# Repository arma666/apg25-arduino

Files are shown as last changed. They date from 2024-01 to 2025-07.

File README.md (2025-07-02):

## Блок управления пилетной горелкой АПГ-25 на основе esp32



Данный блок сделан в экспериментальных целях ради интереса и для хобби. До этого никогда не имел дела с ардуино-лайк, не с паяльником. Так что проект мягко говоря сырой, есть что ещё допиливать. Но тестирование прошёл и он работает.

---

ESP32 имеет встроенныймодуль wifi, но я не использовал его. Мне была принципиальна работа сети по кабелю. Но, если кому-то нужно, такая возможность есть, и в этом случае модуль W5500 можно не покупать.

Делал для своей АПГ-25, но подойдёт на горелки любой мощности.

---

#### _Особености_

*   Все компоненты - готовые модули. Они не распаяны на плате, а вставлены в штыревые разъемы. При выходе из строя любой из них легко заменить.
*   Управление блоком по ethernet кабелю.
*   Простой api на основе get-запросов.

#### _Компоненты_

| Компонент | Ссылка |
| --- | --- |
| ESP32 | [link](https://market.yandex.ru/product--maketnaia-plata-nodemcu-esp32-esp-wroom-32-ch340-type-c-wifi-bluetooth-lua-sverkhnizkoe-energopotreblenie/1790648827?sku=1018809108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) |
| Датчик обнаружения пламени LM393, 4-контактный | [link](https://www.ozon.ru/product/datchik-obnaruzheniya-plameni-lm393-4-kontaktnyy-846693032/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) |
| OLED дисплей 0.96" 128x64, I2C | [link](https://www.ozon.ru/product/oled-displey-0-96-128x64-i2c-goluboy-832377824/) |
| Модуль регулятора напряжения N-MOS | [link](https://www.ozon.ru/product/regulyator-skorosti-dvigatelya-xy-mos-regulyator-napryazheniya-n-mos-pereklyuchatel-1228912589/) |
| Сетевой модуль W5500 | [link](https://market.yandex.ru/product--setevoi-modul-w5500-tcp-ip-stm32-ethernet-dlia-arduino-n/1824023690?sku=101968565885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) |
| Модуль реле твердотельное 12 вольт 2 канала высокоуровневое. | [link](https://www.ozon.ru/product/2-kanalnyy-12v-vysokourovnevoe-upravlenie-postoyannym-tokom-tverdotelnyy-releynyy-1269808418/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). |
| 1-канальный релейный модуль 5V. | [link](https://www.ozon.ru/product/1-kanalnyy-releynyy-modul-5v-5-volt-1-kanal-modul-rele-1-kanal-nagruzka-max-ac-250v-10a-dc-30v-1269506499) |
| Печатная макетная плата для пайки двухсторонняя 9\*15см / зеленая плата под пайку универсальная | [link](https://www.ozon.ru/product/pechatnaya-maketnaya-plata-dlya-payki-dvuhstoronnyaya-9-15sm-zelenaya-plata-pod-payku-universalnaya-1067054329/) |
| Штыревые однорядные разъемы на плату МАМА (PBS-40) 40 pin 2.54 мм, 10 штук | [link](https://www.ozon.ru/product/shtyrevye-odnoryadnye-razemy-na-platu-mama-pbs-40-40-pin-2-54-mm-10-shtuk-pld-razem-dlya-proektov-1051231516/) |
| Клеммная колодка KF235 с пружинным зажимом для пайки на плату 10 контактов | [link](https://www.ozon.ru/product/klemmnaya-kolodka-kf235-s-pruzhinnym-zazhimom-dlya-payki-na-platu-10-kontaktov-764072916/) |
| Клеммная колодка KF202 с пружинным зажимом для пайки на плату 6 контактов | [link](https://www.ozon.ru/product/klemmnaya-kolodka-kf202-s-pruzhinnym-zazhimom-dlya-payki-na-platu-6-kontaktov-764413414/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) |
| Датчик температуры DS18B20 + Модуль для подключения | [link](https://www.ozon.ru/product/datchik-temperatury-ds18b20-modul-dlya-podklyucheniya-832438319/) |
| Блок питания 12В 2А |   |
| Кнопка | [link](https://www.ozon.ru/product/taktovaya-knopka-dip-6mm-h-6mm-h-5mm-kan0611-0431b-komplekt-10sht-1298579180/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) |

#### _Схема_

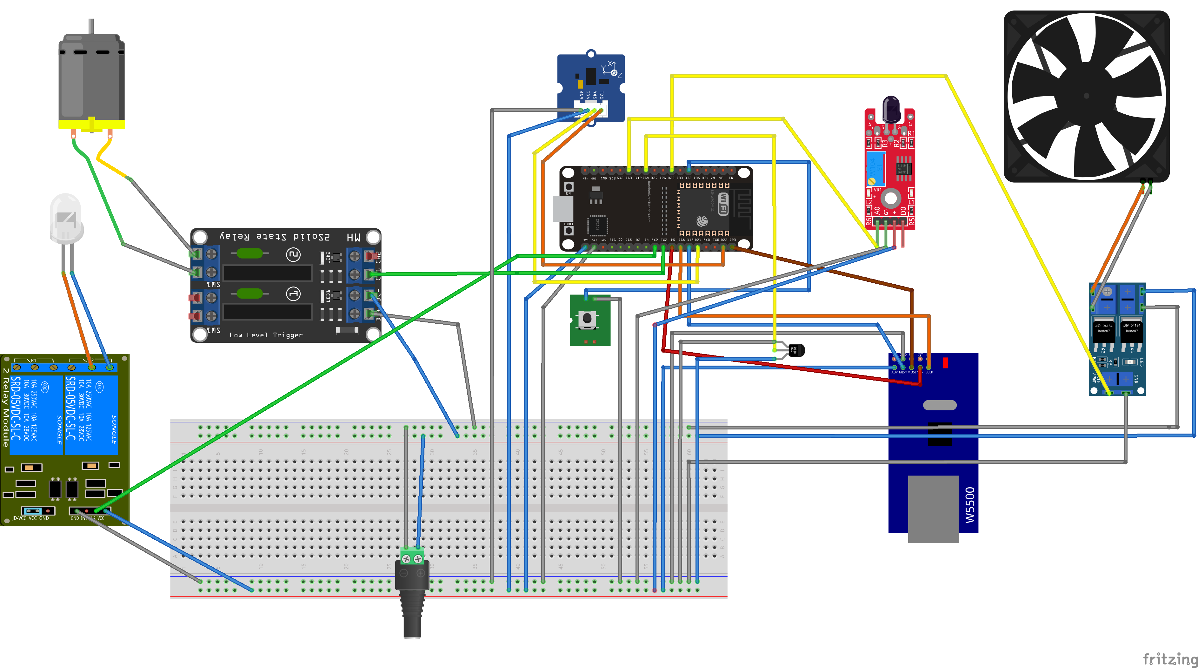
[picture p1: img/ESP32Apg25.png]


Так же схема есть в файле [ESP32Apg25.fzz](https://github.com/arma666/apg25-arduino/blob/main/ESP32Apg25.fzz) для fritzing.

#### _Индикация_

На олед-дисплее простая индикация. Имеется обратный отчёт подкидывания/лампы.   

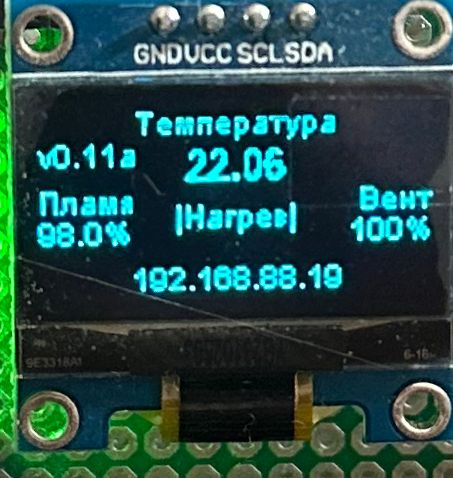
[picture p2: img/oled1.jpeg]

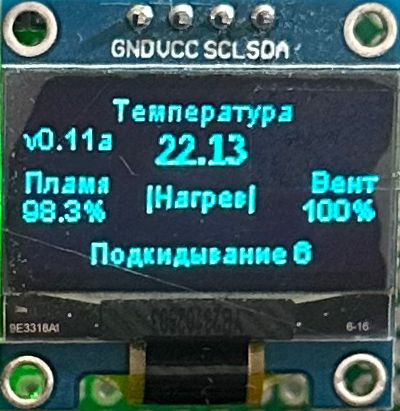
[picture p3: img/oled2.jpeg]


#### Веб-интерфейс

Интуитивно понятный и минималистский. Сам интерфейс храниться на github, и загружается динамически. И как следствие можно его менять не перепрошивая esp32 и даже не выключая. 

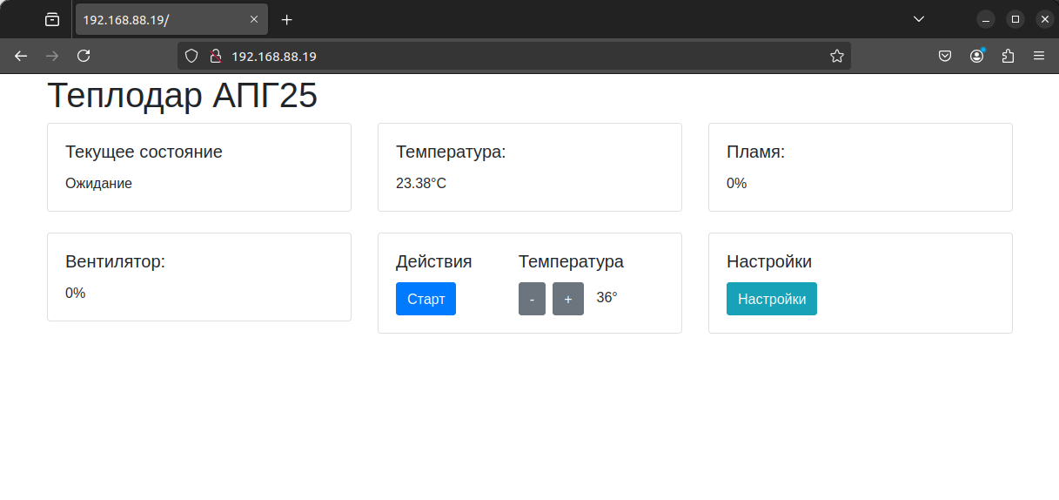
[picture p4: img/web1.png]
 

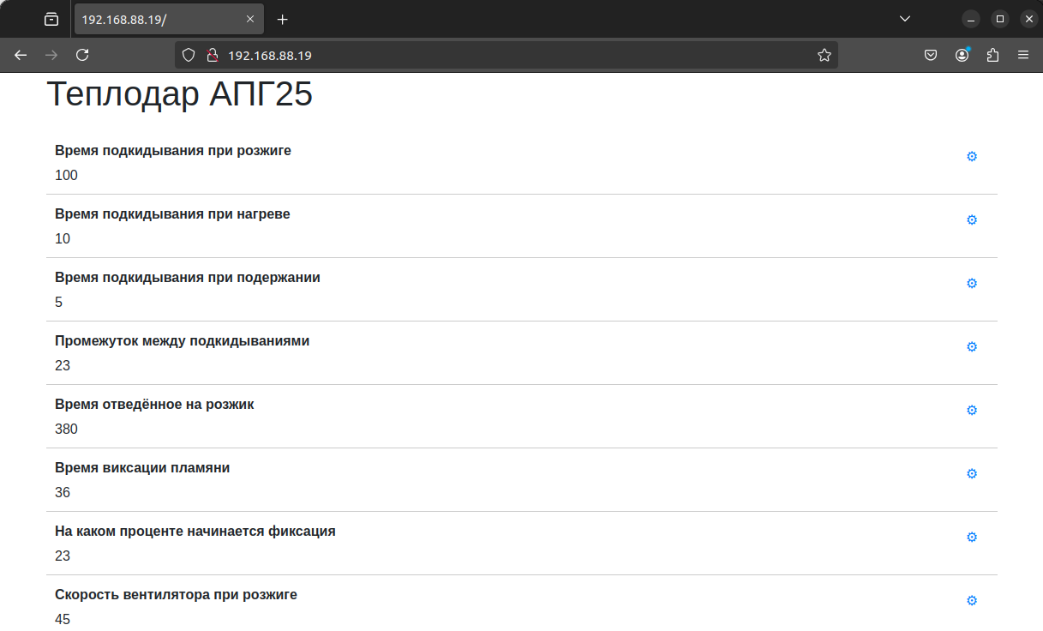
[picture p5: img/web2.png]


#### _API_

_(дополнить)_

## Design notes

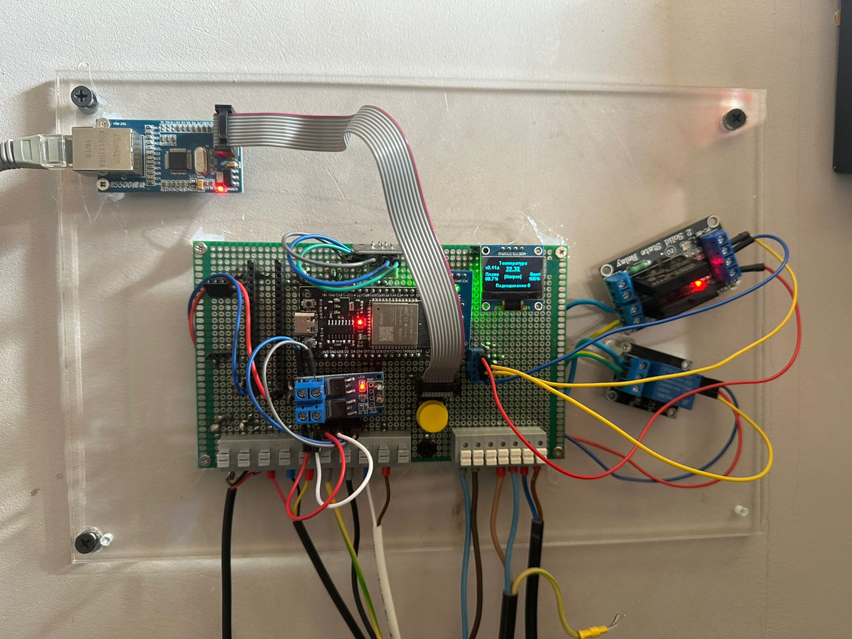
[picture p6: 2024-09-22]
img/full.jpeg

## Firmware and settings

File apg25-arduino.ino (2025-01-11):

String VERSION="v0.122a";

#include <SSD1306Wire.h>
#include "fontsRus.h"
#include "fonts.h"
//#include <EEPROM.h>
#include <ArduinoJson.h>
#include <SPIFFS.h>
#include <SPI.h>
#include <Ethernet2.h>
// Перезагрузка интерфейса
unsigned long lastResetTime = 0;
unsigned long resetInterval = 900000;   // Интервал перезагрузки (15 минут)
//


//Расход
unsigned long throwTime = 0; //Накопление
unsigned long throwTimemillis = 0;
float throwPersent = 0;
///////
unsigned long trozhTemp = 0;

byte rAddr= 0;
SSD1306Wire display(0x3c, SDA, SCL); // SDA - IO5 (D1), SCL - IO4 (D2) 

// Температура ------------------------->
#include <OneWire.h>
OneWire  ds(14);
byte addr[8];
float temperVal = 0; // Глобальная температура
//<---------------------------------

//Настройки
struct OPT {
  unsigned long  Tshnek;
  unsigned long  Trozhik;
  unsigned long  Tflamefix;
  unsigned long  waitTshnek;
  unsigned long Tflame;//Сколько времени нет пламени
  unsigned long Tvizh;
  unsigned long  TFlame; 
  unsigned long TTemp;
  unsigned long timer500;
  unsigned long Tbtn;
  float flamePersent = 0;
  byte vspeed = 0;
  String defIP = "-.-.-.-";
  unsigned long countTimer;
  byte rozhikCount = 0;
  boolean isnet = false; 
  /*
Режимы - -
  0 - Ожидание
  1 - Розжик
  2 - Нагрев
  3 - Поддержание
  4 - Выжигание
  5 - Ошибка розжига
  6 - Ошибка пламени
*/
  byte regim;
  byte prregim;
  boolean isstart = true;
};
OPT opt;
//Настройки ------------>
struct SETTINGS {
  byte troz_sh; //Время подкидывания при розжиге 
  byte tnag_sh; //Время подкидывания при нагреве
  byte tpod_sh; //Время подкидывания при подержании
  byte tsh_st; //Промежуток между подкидываниями
  unsigned long troz; //Время отведённое на розжик
  byte fl_fix; //Время виксации пламяни
  byte tfl; //На каком проценте начинается фиксация
  byte vroz; //скорость вентилятора при розжиге
  byte v_nag; //скорость вентилятора при нагреве
  byte v_pod; //скорость вентилятора при поддержании
  byte v_og; //скорость вентилятора при ожидании
  byte temp; //Установка температуры
  byte gister; //Гистерезис
  byte t_vizh; //Время выжигания после пламя = 0
  byte t_max; //температура перегрева
};

SETTINGS defaultSettings = {
  90, //Время подкидывания при розжиге 
  11, //Время подкидывания при нагреве
  4, //Время подкидывания при подержании
  27, //Промежуток между подкидываниями
  1200, //Время отведённое на розжик
  100, //Время фиксации пламяни
  20, //На каком проценте начинается фиксация
  75, //скорость вентилятора при розжиге
  100, //скорость вентилятора при нагреве
  80, //скорость вентилятора при поддержании
  0, //скорость вентилятора при ожидании
  49, //Установка температуры
  4, //Гистерезис
  180, //Время выжигания после пламя = 0
  70 //температура перегрева
};
SETTINGS conf; 

// Датчик огня ----------->
byte analogPin = 13;
//String flame = "0";
//<------------------------

// Реле ------------>
const byte shnek = 17;
const byte lampa = 16;
bool shnekStart = false;
bool lampaStart = false;
//<------------------------

// Кнопка ----------->
bool bflag = false;
byte bpin = 32;
//<------------------------

// Вентилятор ----------->
const byte vent = 25;
byte vspeed = 0; //скорость вентилятора в процентах
byte vspeedtemp = 0;
//<------------------------


// MAC-адрес вашего Arduino
byte mac[] = {0xDE, 0xAD, 0xBE, 0xEF, 0x29, 0xED};

// Создаем сервер на порту 80
EthernetServer server(80);
byte serverPort = 80;
EthernetClient client;


//Функция инициализации сети
void netstart(){
  //Serial.println("y");
  Ethernet.init(5);
  //Serial.println("x");
  if (Ethernet.begin(mac) == 0) {
    ////Serial.println("Failed to configure Ethernet using DHCP");
    // Некоторые дополнительные действия при ошибке
    opt.defIP="No ip :(";
    //for(;;);
  } else {
    //My IP address:
    opt.defIP = "";
    for (byte thisByte = 0; thisByte < 4; thisByte++) {
      opt.defIP+=Ethernet.localIP()[thisByte];
      if (thisByte < 3) {
        opt.defIP+=".";
      }
    }
    opt.isnet=true;
    // Начинаем слушать порт 80
    server.begin();
  }
}

void netreset(){
  if (millis() - lastResetTime >= resetInterval) {
      lastResetTime = millis();  
      netstart(); 
    }
}

int percentToValue(int percent) { //Функция перевода процентов в число для вкентилятора
  if (percent == 0){
    return 0;
  } else {
    return map(percent, 0, 100, 73, 255);
  }
}

//Запись режима
void rwrite(){
  File regim = SPIFFS.open("/regim", "w");
  regim.write(opt.regim);
  regim.close();

}
void rload(){
  File regim = SPIFFS.open("/regim", "r");
  if (!regim) {
    File regim = SPIFFS.open("/regim", "w");
    regim.write(0);
    regim.close();
  } else {
    opt.regim = regim.read();
    regim.close();
  }
}



void setup() {
  // esp_task_wdt_init();
  // esp_task_wdt_add(NULL);
  //Serial.begin(115200);
  //Сеть
  netstart();
  //Вентилятор
  pinMode(vent, OUTPUT);

  //Реле
  pinMode(lampa, OUTPUT);    
  pinMode(shnek, OUTPUT);  
  digitalWrite(lampa, LOW); // Выключаем реле
  digitalWrite(shnek, LOW); // Выключаем реле 
  //Читаем из памяти
  if (!SPIFFS.begin(true)) {
    //Serial.println("An error occurred while mounting SPIFFS");
    return;
  }
  
  if (!loadSettings()) {
    conf = defaultSettings;
    saveSettings();
  }
  
  //Кнопка
  pinMode(bpin, INPUT_PULLUP); 

  //Дисплей
  display.init(); //  Инициализируем дисплей
  display.flipScreenVertically(); // Устанавливаем зеркальное отображение экрана
  display.setFontTableLookupFunction(FontUtf8Rus);

  //Загрузка режима
  rload();

  //Проверяем пламя
  flameGet();
  checkstart();

}

void checkstart(){
  if (opt.flamePersent>0){ //Если есть плямя
    if (opt.regim == 2 || opt.regim == 3 ){ //Если до перезагрузки был режим 2 или 3
      opt.prregim = 14; //ВОзращаем печку в режим 
    }
    if (opt.regim == 4) { //Если стояло выжигание
      opt.prregim = 8;
    }
    if (opt.regim == 1){ //Если тоял розжик
      opt.prregim = 8;
    }
    if (opt.regim == 6) { //Если ошибка пламени при работе
      opt.prregim = 14;
    }
  } else { //Если пламени нет
     if (opt.regim == 2 || opt.regim == 3 || opt.regim == 6) { //Если до рестарта горело или ошибка пламени при работе, тогда розжик
      opt.regim = 1;
      opt.prregim = 10;
     } else {
      opt.regim = 0;
      opt.prregim = 0;
      opt.Tflame=0;
      shnekStart=false;
      lampaStart=false;
      vspeedtemp = 0;
     }
  }
  rwrite();

}

String x = "";
bool loadSettings() {
  File configFile = SPIFFS.open("/conf1.json", "r");
  if (!configFile) {
    return false;
  }

  size_t size = configFile.size();
  if (size == 0) {
    return false;
  }

  std::unique_ptr<char[]> buf(new char[size]);
  configFile.readBytes(buf.get(), size);
  x=buf.get();
  StaticJsonDocument<1024> doc;
  DeserializationError error = deserializeJson(doc, buf.get());
  if (error) {
    //Serial.println("Failed to parse config file");
    return false;
  }

  conf.troz_sh = doc["troz_sh"] | defaultSettings.troz_sh;
  conf.tnag_sh = doc["tnag_sh"] | defaultSettings.tnag_sh;
  conf.tpod_sh = doc["tpod_sh"] | defaultSettings.tpod_sh;
  conf.tsh_st = doc["tsh_st"] | defaultSettings.tsh_st;
  conf.troz = doc["troz"] | defaultSettings.troz;
  conf.fl_fix = doc["fl_fix"] | defaultSettings.fl_fix;
  conf.tfl = doc["tfl"] | defaultSettings.tfl;
  conf.vroz = doc["vroz"] | defaultSettings.vroz;
  conf.v_nag = doc["v_nag"] | defaultSettings.v_nag;
  conf.v_pod = doc["v_pod"] | defaultSettings.v_pod;
  conf.v_og = doc["v_og"] | defaultSettings.v_og;
  conf.temp = doc["temp"] | defaultSettings.temp;
  conf.gister = doc["gister"] | defaultSettings.gister;
  conf.t_vizh = doc["t_vizh"] | defaultSettings.t_vizh;
  conf.t_max = doc["t_max"] | defaultSettings.t_max;
  
  

  configFile.close();
  return true;
}

void saveSettings() {
  File configFile = SPIFFS.open("/conf1.json", "w");
  if (!configFile) {
    //Serial.println("Failed to open config file for writing");
    return;
  }

  StaticJsonDocument<1024> doc;
  doc["troz_sh"] = conf.troz_sh;
  doc["tnag_sh"] = conf.tnag_sh;
  doc["tpod_sh"] = conf.tpod_sh;
  doc["tsh_st"] = conf.tsh_st;
  doc["troz"] = conf.troz;
  doc["fl_fix"] = conf.fl_fix;
  doc["tfl"] = conf.tfl;
  doc["vroz"] = conf.vroz;
  doc["v_nag"] = conf.v_nag;
  doc["v_pod"] = conf.v_pod;
  doc["v_og"] = conf.v_og;
  doc["temp"] = conf.temp;
  doc["gister"] = conf.gister;
  doc["t_vizh"] = conf.t_vizh;
  doc["t_max"] = conf.t_max;

  if (serializeJson(doc, configFile) == 0) {
    //Serial.println("Failed to write to config file");
  }

  configFile.close();
}



void Display(){
  display.clear(); // Очищаем экран
  display.setFont(ArialRus_Plain_10); // Шрифт кегль 10
  display.setTextAlignment(TEXT_ALIGN_CENTER);
  display.drawString(display.getWidth() / 2, 0, "Температура");
  display.setFont(Arimo_Bold_13);
  display.drawString(display.getWidth() / 2, 13, String(temperVal));
  //Версия
  display.setFont(ArialRus_Plain_10); 
  display.setTextAlignment(TEXT_ALIGN_LEFT);
  display.drawString(0, 10, VERSION);
  //Пламя
  display.setFont(ArialRus_Plain_10); 
  display.setTextAlignment(TEXT_ALIGN_LEFT);
  display.drawString(0, 25, "Пламя");
  display.drawString(0, 35, String(opt.flamePersent,1)+"%");
  //Вентилятор
  display.setTextAlignment(TEXT_ALIGN_RIGHT);
  display.drawString(display.getWidth(), 25, "Вент");
  display.drawString(display.getWidth(), 35, String(vspeed)+"%");
  //Режим
  String regimStr;
  switch (opt.regim) {
    case 0:
      regimStr = F("|Ожидание|");
    break;
    case 1:
      regimStr = "|Розжик "+String(opt.rozhikCount+1)+ "|";
    break;
    case 2:
      regimStr = F("|Нагрев|");
    break;
    case 3:
      regimStr = F("|Поддерж|");
    break;
    case 4:
      regimStr = F("|Выжигание|");
    break;
    case 5:
      regimStr = F("|Ошибка|");
    break;
    }
  display.setTextAlignment(TEXT_ALIGN_CENTER);
  display.drawString(display.getWidth() / 2, 30, regimStr);
  String status;
  switch (opt.prregim) {
    case 10:
      status = F("Подкидывание");
    break;
    case 11:
      status = "Подкидывание "+String(opt.countTimer);
    break;
    case 12:
      status = "Лампа "+String(opt.countTimer);
    break;
    case 13:
      status = F("Вижу пламя - фиксация");
    break;
    case 14:
      status = F("Разгорелось!");
    break;
    case 21:
      status = "Подкидывание "+String(opt.countTimer);
    break;
    case 22:
      status = "Подкидывание "+String(opt.countTimer);
    break;
    case 31:
      status = "Подкидывание "+String(opt.countTimer);
    break;
    case 32:
      status = "Подкидывание "+String(opt.countTimer);
    break;
    case 80:
      status = "Перегрев!!!!";
    break;
    default:
      status = opt.defIP;
  }
  display.drawString(display.getWidth() / 2, 50, status);

  display.display(); // Выводим на экран
}



void loop() {
  if (opt.isnet)
  {
    web();
  } else 
  {
    netstart();
  }
  
  
  
  if (millis() - opt.TTemp >= 5000) {
    netreset();
    opt.TTemp = millis();
    temperVal = TempGetTepr();
    //Если перегрев
    if (temperVal>conf.t_max) {
      opt.prregim = 80;
    }
  }
  
  if (millis() - opt.timer500 >= 500) {
    opt.timer500=millis();
    flameGet();
    rele();
    Display();
    Vent();
    flamecheck();
    control();
  }

  //блок кнопки
  bool btnState = !digitalRead(bpin);
  if (btnState && !bflag && millis() - opt.Tbtn > 100) { //Кнопку нажали
    bflag = true;
    opt.Tbtn = millis();
  } 
  if (!btnState && bflag && millis() - opt.Tbtn > 100) {  //Кнопку отпустили
    bflag = false;
    opt.Tbtn = millis();
    pressputton();
  }
}


//Функция проверки не патух ли котел
void flamecheck(){
  if (opt.regim && opt.regim!=1 && opt.regim!=5 && opt.regim!=4 && !opt.Tflame){
    if (opt.flamePersent < conf.tfl) {
          //Если пламя пропало, то возможно его забросало и оно разгориться, ждём 45 секунд
          opt.Tflame=millis();
    }
  }
  if (opt.Tflame && opt.Tflame+(45*1000L)<millis()){
    if (opt.flamePersent < conf.tfl){
      //не разожглось, уходим в ошибку
      shnekStart=false;
      opt.prregim = 19;
      opt.regim = 6;
      rwrite();
      lampaStart=false;
      opt.Tflame=0;
      ESP.restart();
    } else {
      opt.Tflame=0;
    }
  }
}


//Основная функция управления 
void control() {
  ////Serial.println(String(opt.prregim));
  switch (opt.prregim) {
      //Перегрев
      case 80:
        shnekStart=false;
        lampaStart=false;
        vspeedtemp = 100;
      break;
      case 8: //Выжигание, ждём когда погаснет
        if (opt.flamePersent == 0) {
          opt.Tvizh = millis();
          opt.prregim = 9;
        }
      break;
      case 9: //
        if (opt.Tvizh+(conf.t_vizh*1000L)<millis()){
          opt.prregim = 0;
          opt.regim = 0;
          rwrite();
          shnekStart=false;
          lampaStart=false;
          vspeedtemp = 0;
          ESP.restart();
        }
      break;
      //10-11 подкидывание при розжиге
      case 10:
        if (opt.rozhikCount) {
            trozhTemp = 10;
        } else {
            trozhTemp = conf.troz_sh;
        }
        opt.prregim = 11;
        shnekStart=true;
        opt.Tshnek = millis();
        //opt.countTimer=trozhTemp;
      break;
      case 11:
        opt.countTimer=(opt.Tshnek+(trozhTemp*1000L) - millis())/1000;
        if (opt.Tshnek+(trozhTemp*1000L) < millis()) {
          shnekStart=false;
          lampaStart=true;
          vspeedtemp = conf.vroz;
          opt.prregim = 12;
          opt.Trozhik = millis();
        }
      break;
      //Подкидывание закончилось, лампа, ждём когда увидим пламя
      case 12:
        opt.countTimer=(opt.Trozhik+(conf.troz*1000L) - millis())/1000;
        //Лампа не больше 300 секунд
        // if (opt.Trozhik+300*1000L<millis()){
        //   lampaStart=false;
        // }
        if (opt.Trozhik+(conf.troz*1000L) < millis()){
          ////Serial.println("fuck");
          if (!opt.rozhikCount) {
            opt.rozhikCount++;
            lampaStart=false;
            opt.prregim = 10;
          } else {
            opt.rozhikCount=0;
            opt.prregim = 19;
            opt.regim = 5;
            rwrite();
            lampaStart=false;
          }
        }
        if (opt.flamePersent > conf.tfl) {
          opt.Tflamefix = millis();
          opt.prregim = 13;
        }
      break;
      case 13:
        if (opt.flamePersent > conf.tfl && opt.Tflamefix+(conf.fl_fix*1000L)< millis()) {
          //Если разгорелось
          lampaStart=false;
          opt.prregim = 14;
        }
        if (opt.flamePersent < conf.tfl) {
          //Если пламя пропало
          opt.prregim = 12;
        }
      break;
      case 14:
        throwTimemillis = millis();
        if (temperVal>conf.temp-conf.gister) {
          //Если болше заданной температуры то поддержка
          opt.regim = 3;
          rwrite();
          opt.prregim = 30;
        } else {
          opt.regim = 2;
          rwrite();
          opt.prregim = 20;
        }
      break;
      case 20:
        vspeedtemp = conf.v_nag;
        opt.prregim = 21;
      break; 
      case 21: 
        if (temperVal>conf.temp) { //Если температура богльше то режим поддержания
          opt.regim = 3;
          rwrite();
          opt.prregim = 30;
        } else {
          shnekStart=true;
          opt.Tshnek = millis();
          opt.prregim = 22;
        }
      break;
      case 22: 
        opt.countTimer=(opt.Tshnek+(conf.tnag_sh*1000L) - millis())/1000;
        if (opt.Tshnek+(conf.tnag_sh*1000L)<millis()){
          throwTime+=conf.tnag_sh*1000L;
          throwPersent = throwTime * 100.0 / (millis()-(float)throwTimemillis);
          shnekStart=false;
          opt.waitTshnek = millis();
          opt.prregim = 23;
        }
      break;
      case 23: 
        if (temperVal>conf.temp) { //Если температура богльше то режим поддержания
          opt.regim = 3;
          rwrite();
          opt.prregim = 30;
        }
        if (opt.waitTshnek+(conf.tsh_st*1000L)<millis()){
          opt.prregim = 21;
        }
      break;
      case 30: 
        vspeedtemp = conf.v_pod;
        opt.prregim = 31;
      break;
      case 31: 
        if (temperVal<conf.temp-conf.gister) { //Если темп меньше гистерезиса то нагрев
          opt.regim = 2;
          rwrite();
          opt.prregim = 20;
        } else {
          shnekStart=true;
          opt.Tshnek = millis();
          opt.prregim = 32;
        }
      break;
      case 32: 
        opt.countTimer=(opt.Tshnek+(conf.tpod_sh*1000L) - millis())/1000;
        if (opt.Tshnek+(conf.tpod_sh*1000L)<millis()){
          throwTime+=conf.tpod_sh*1000L;
          throwPersent = throwTime * 100.0 / (millis()-(float)throwTimemillis);
          shnekStart=false;
          opt.waitTshnek = millis();
          opt.prregim = 33;
        }
      break;
      case 33: 
        if (temperVal<conf.temp-conf.gister) { //Если темп меньше гистерезиса то нагрев
          opt.regim = 2;
          rwrite();
          opt.prregim = 20;
        }
        if (opt.waitTshnek+(conf.tsh_st*1000L)<millis()){
          opt.prregim = 31;
        }
      break;
  }
}

//Блок вентилятора
void Vent(){
  if (vspeed != vspeedtemp) {
    vspeed = vspeedtemp;
    analogWrite(vent, 255);
  } else {
    analogWrite(vent, percentToValue(vspeed));
  }
}

//Функция нажатия кнопки --------------->
void pressputton(){
  if (opt.regim == 0 ){
    opt.regim = 1;
    opt.prregim =10;
  } else if (opt.regim == 4 || opt.regim == 5) {
    opt.regim = 0;
    opt.prregim = 0;
    opt.Tflame=0;
    shnekStart=false;
    lampaStart=false;
    vspeedtemp = 0;
  }
  else {
    //byte tregim = opt.regim;
    opt.regim = 4;
    opt.prregim = 8;
    opt.Tflame = 0;
    lampaStart=false;
    shnekStart=false;
    vspeedtemp = 100;
  }

  rwrite();
}

//блок реле
void rele(){
  if (shnekStart){  
    digitalWrite(shnek, HIGH); // Включаем реле
  } else {
    digitalWrite(shnek, LOW); // Выключаем реле
  }
  if (lampaStart) {
    digitalWrite(lampa, HIGH); // Выключаем реле
  } else {
    digitalWrite(lampa, LOW); // Выключаем реле
  }
}
char FontUtf8Rus(const byte ch) { 
    static uint8_t LASTCHAR;

    if ((LASTCHAR == 0) && (ch < 0xC0)) {
      return ch;
    }

    if (LASTCHAR == 0) {
        LASTCHAR = ch;
        return 0;
    }

    uint8_t last = LASTCHAR;
    LASTCHAR = 0;
    
    switch (last) {
        case 0xD0:
            if (ch == 0x81) return 0xA8;
            if (ch >= 0x90 && ch <= 0xBF) return ch + 0x30;
            break;
        case 0xD1:
            if (ch == 0x91) return 0xB8;
            if (ch >= 0x80 && ch <= 0x8F) return ch + 0x70;
            break;
    }

    return (uint8_t) 0;
}


//получение огня
void flameGet() {
  float rawValue = analogRead(analogPin) / 4095.0;
  opt.flamePersent = 100 - pow(rawValue, 2) * 100;
  if (opt.flamePersent > 100) opt.flamePersent = 100;
  if (opt.flamePersent < 0) opt.flamePersent = 0;
}

// Получение температуры---------------->
float TempReturn() {
  byte i;
  byte present = 0;
  byte data[12];
  present = ds.reset();
  ds.select(addr);    
  ds.write(0xBE); 
  for ( i = 0; i < 9; i++) {           // we need 9 bytes
    data[i] = ds.read();
  }
  int16_t raw = (data[1] << 8) | data[0];
  byte cfg = (data[4] & 0x60);
  if (cfg == 0x00) raw = raw & ~7;  // 9 bit resolution, 93.75 ms
  else if (cfg == 0x20) raw = raw & ~3; // 10 bit res, 187.5 ms
  else if (cfg == 0x40) raw = raw & ~1; // 11 bit res, 375 ms
  return (float)raw / 16.0;
}

float Tempwait1 (int x, uint32_t m) {
  if (m - millis() >= x) {
    ////Serial.println("yes");
    return TempReturn();
  } else {
    ////Serial.println("no");
    return Tempwait1(x,m);
  }
}


float TempGetTepr() {
  if (!ds.search(addr)) {
    return TempGetTepr();
  } else {
    ds.reset();
    ds.select(addr);
    ds.write(0x44, 1);
    return Tempwait1(1000, millis());
  }
}
//<----------------------------------------


//Функция веб-морды --------------->
void web(){
  EthernetClient ethClient = server.available();
  if (ethClient) {
    if (ethClient.available()) {
      String request = ethClient.readStringUntil('\r');
      ethClient.flush();
      if (processSettingsUpdate(request)){
        if (sendparams(ethClient,request)){
          if (sendst(ethClient,request)){
            if (webpressbutton(ethClient,request)){
               sendSettingsPage(ethClient);
            }
          }
       }
      } 
    while (ethClient.available()) {
        ethClient.read();
    }

    // Закрываем соединение
    ethClient.stop();
    }
  }
}

boolean webpressbutton(EthernetClient& ethClient, String request) {
  if (request.indexOf("perssbutton") != -1 ){
    pressputton();
  return false;
  } else {
    return true;
  }
}


//Посылаем текущее состояние
boolean sendst(EthernetClient& ethClient, String request) {
  if (request.indexOf(F("getstate")) != -1 ){
    ethClient.println(F("HTTP/1.1 200 OK"));
    ethClient.println(F("Content-Type: text/JSON"));
    ethClient.println();
    ethClient.print("{");
    ethClient.print("\"regim\":" + String(opt.regim) + ",");
    ethClient.print("\"shnekStart\":" + String(shnekStart) + ",");
    ethClient.print("\"lampaStart\":" + String(lampaStart) + ",");
    ethClient.print("\"vspeed\":" + String(vspeed) + ",");
    ethClient.print("\"flamePersent\":" + String(opt.flamePersent) + ",");
    ethClient.print("\"throwPersent\":" + String(throwPersent) + ",");
    ethClient.print("\"temperVal\":" + String(temperVal) + "}");
    return false;
  } else {
    return true;
  }
}
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

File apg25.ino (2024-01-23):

#include <SPI.h>
#include <Ethernet2.h>
#include <EEPROM.h>
int myregimAddr= 0;
int mySettingAddr = sizeof(int);

uint32_t myTimerFlame, myTimertemp, myTimerDIsplay, myTimerVent, btnTimer, releTimer;
uint32_t regimTimer, shnekTimer,rozhikTimer, flamefixTimer, waitshnekTimer, flameTimer=0, vizhTimer;
//Настройки ------------>
struct SETTINGS {
  int t_rozhik_shnek; //Время подкидывания при розжиге 
  int t_nagrev_shnek; //Время подкидывания при нагреве
  int t_podderg_shnek; //Время подкидывания при подержании
  int t_shnek_step; //Промежуток между подкидываниями
  int t_rozhik; //Время отведённое на розжик
  int flame_fix; //Время виксации пламяни
  int t_flame; //На каком проценте начинается фиксация
  int vent_rozhik; //скорость вентилятора при розжиге
  int vent_nagrev; //скорость вентилятора при нагреве
  int vent_podderg; //скорость вентилятора при поддержании
  int vent_ogidanie; //скорость вентилятора при ожидании
  int temp; //Установка температуры
  int gister; //Гистерезис
  int t_vizh; //Время выжигания после пламя = 0
};

SETTINGS conf = {
  2, //Время подкидывания при розжиге 
  8, //Время подкидывания при нагреве
  5, //Время подкидывания при подержании
  10, //Промежуток между подкидываниями
  50, //Время отведённое на розжик
  10, //Время виксации пламяни
  5, //На каком проценте начинается фиксация
  30, //скорость вентилятора при розжиге
  100, //скорость вентилятора при нагреве
  75, //скорость вентилятора при поддержании
  0, //скорость вентилятора при ожидании
  30, //Установка температуры
  4, //Гистерезис
  10 //Время выжигания после пламя = 0
};
//<------------------------

//Режим ------------>
int regim;
int prregim = 0;
int rozhikCount = 0;
/*
Режимы - -
  0 - Ожидание
  1 - Розжик
  2 - Нагрев
  3 - Поддержание
  4 - Выжигание
  5 - Ошибка розжига
*/
// Реле ------------>
int shnek = 8;
int lampa = 7;
bool shnekStart = false;
bool lampaStart = false;
//<------------------------
// Кнопка ----------->
bool bflag = false;
//<------------------------


// Вентилятор ----------->
int vent = 5;
int vspeed = 0; //скорость вентилятора в процентах
int vspeedtemp = 0;
//<------------------------


// Датчик огня ----------->
int analogPin = A0;
String flame = "0";
float flamePersent = 0; //Глобальная пламя
//<------------------------

// Температура ------------------------->
#include <OneWire.h>
OneWire  ds(3);
byte addr[8];
float temperVal = 0; // Глобальная температура
//<---------------------------------


// Дисплей ------------------------->
#include <OLED_I2C.h>
OLED  myOLED(SDA, SCL); 
extern uint8_t SmallFont[];
extern uint8_t RusFont[]; // Русский шрифт
extern uint8_t MediumNumbers[]; // Подключение больших шрифтов
extern uint8_t SmallFont[]; // Базовый шрифт без поддержки русскийх символов.

//<---------------------------------

int percentToValue(int percent) { //Функция перевода процентов в число для вкентилятора
  if (percent == 0){
    return 0;
  } else {
    return map(percent, 0, 100, 73, 255);
  }
}

void setup()
{
  //Читае настройки из памяти
  regim = EEPROM.read(myregimAddr);
   if (regim == 0xFF) {
    regim = 0;
    EEPROM.write(myregimAddr, regim);
  } 


  pinMode(lampa, OUTPUT);    
  pinMode(shnek, OUTPUT);    
  digitalWrite(lampa, HIGH); // Выключаем реле
  digitalWrite(shnek, HIGH); // Выключаем реле

  myOLED.begin(); 
  pinMode(vent, OUTPUT); 
  analogWrite(vent, percentToValue(0));
  pinMode(4, INPUT_PULLUP); //Кнопка
  //Serial.begin(9600);

  //Блок какой режим был до выключения
  if (regim==1 || regim==2 ||regim==3){
    int flametemp = flameGet();
    //Проверяем есть ли пламя
    if (flametemp>conf.t_flame) { //пламя больше пламени фиксации
      regim = 1;
      EEPROM.write(myregimAddr, regim);
      prregim =14;
    }
    if (flametemp<conf.t_flame){ //если меньше - режим розжига
      regim = 1;
      EEPROM.write(myregimAddr, regim);
      prregim =10;
    }
  }
  if (regim == 4){
    prregim = 8;
    flameTimer = 0;
    lampaStart=false;
    shnekStart=false;
    vspeedtemp = 100;
  }

}




//Функция нажатия кнопки --------------->
void pressputton(){
  if (regim == 0 ){
    regim = 1;
    EEPROM.write(myregimAddr, regim);
    prregim =10;
  } else if (regim == 4 || regim == 5) {
    regim = 0;
    EEPROM.write(myregimAddr, regim);
    prregim = 0;
    flameTimer=0;
    shnekStart=false;
    lampaStart=false;
    vspeedtemp = 0;
  }
  else {
    int tregim = regim;
    regim = 4;
    EEPROM.write(myregimAddr, regim);
    prregim = 8;
    flameTimer = 0;
    lampaStart=false;
    shnekStart=false;
    vspeedtemp = 100;
  }
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

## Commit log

2024-01-24 Обратный отчёт
2024-02-06 Update apg25-arduino.ino
    btn add
2024-02-11 to Esp32
    [ESP32Apg25.fzz, NanoApg25.fzz, Schaltplan.fzz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]
2024-05-08 реле на твердотельное
    [ESP32Apg25.fzz]
2024-09-22 sh up
    [ESP32Apg25.fzz]
2024-10-09 Изменил алгоритм розжига
2024-10-09 Revert "Update apg25-arduino.ino"
    This reverts commit 776c9efa54e974f6b9614c5022bc4a92c39f6fc0.
    [apg25-arduino.ino]
2024-10-25 Добавил расчёт расхода
2024-10-25 rozh
    Второй розжик - 10 секунд подкидывания
2025-01-06 restart after power off
